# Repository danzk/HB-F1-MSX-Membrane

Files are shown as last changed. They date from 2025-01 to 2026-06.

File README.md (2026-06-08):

# MSX Hit Bit Keyboard Membranes

Replacement keyboard membranes for Sony MSX "Hit Bit" home computers.

This repository hosts one design per machine, each in its own directory, all
sharing a common KiCad footprint library.

## Variants

| Machine | Directory | Notes |
| --- | --- | --- |
| Sony HB-F1 | [hb-f1/](hb-f1/) | Original design |
| Sony HB-F1II | [hb-f1ii/](hb-f1ii/) | Reworked PCB with revised switch footprint |

Each variant directory contains its own `pcb/` (KiCad project), `gerber/`
(fabrication outputs) and `mech/` (mechanical drawings), plus a `doc/`
folder for any variant-specific images. Reference material and renders
shared across variants live in the top-level [doc/](doc/) directory.

## Shared footprint library

Both projects reference the same footprints in
[footprints/Sony_Hit_Bit.pretty/](footprints/Sony_Hit_Bit.pretty/) via each
project's `fp-lib-table` (`${KIPRJMOD}/../../footprints/Sony_Hit_Bit.pretty`).

## Manufacturing

See [doc/MANUFACTURING.md](doc/MANUFACTURING.md) for how to order the membrane
from JLCPCB as a 2-layer flexible PCB (stackup, order settings and stiffener
details).

## Other projects

Related keyboard membrane / replacement projects for other Sony MSX models:

- [RBSC/KeyboardMembrane_SonyF1Xx](https://github.com/RBSC/KeyboardMembrane_SonyF1Xx)
  — replacement membrane PCB and gerbers for the Sony HB-F1XV, HB-F1XD and
  HB-F1XDJ.
- [S0urceror/HB-F1XD-keyboard](https://github.com/S0urceror/HB-F1XD-keyboard)
  — KiCad PCB replacement for the Sony HB-F1XD MSX2 keyboard membrane.

## Tooling

2D mechanical drawings were performed with QCAD v3.31.2.7 — https://www.qcad.org/

Electronics were designed with KiCad v8.0.7 — https://www.kicad.org/

The PCB layout uses the font IBM Plex Sans — https://www.ibm.com/plex/

## Licence

Copyright Alexander Knapik 2025.

This source describes Open Hardware and is licensed under the CERN-OHL-W v2 or later.

You may redistribute and modify this documentation and make products
using it under the terms of the CERN-OHL-W v2 (https://cern.ch/cern-ohl).
This documentation is distributed WITHOUT ANY EXPRESS OR IMPLIED
WARRANTY, INCLUDING OF MERCHANTABILITY, SATISFACTORY QUALITY
AND FITNESS FOR A PARTICULAR PURPOSE. Please see the CERN-OHL-W v2
for applicable conditions.

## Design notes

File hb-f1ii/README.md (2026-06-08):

# MSX HB-F1II Keyboard Membrane

A replacement keyboard membrane for the Sony HB-F1II MSX home computer.

This variant reworks the HB-F1 PCB and uses the revised `Switch 2` footprint
from the shared footprint library.

See the [repository README](../README.md) for tooling and licence information.

**Warning this membrane has not yet been tested on real hardware!**

The source image for the HB-F1II is skewed, so there is no guarantee that the footprints for the arrow keys are in the correct location. 

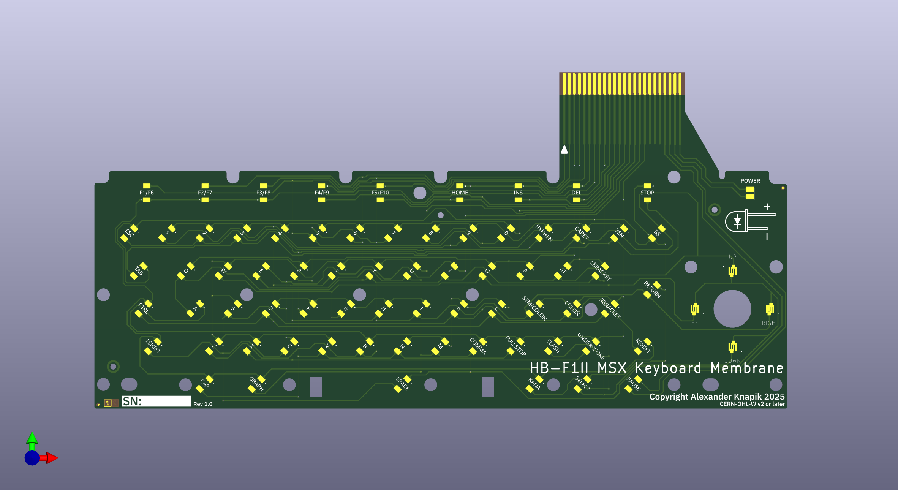
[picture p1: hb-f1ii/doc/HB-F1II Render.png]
Render

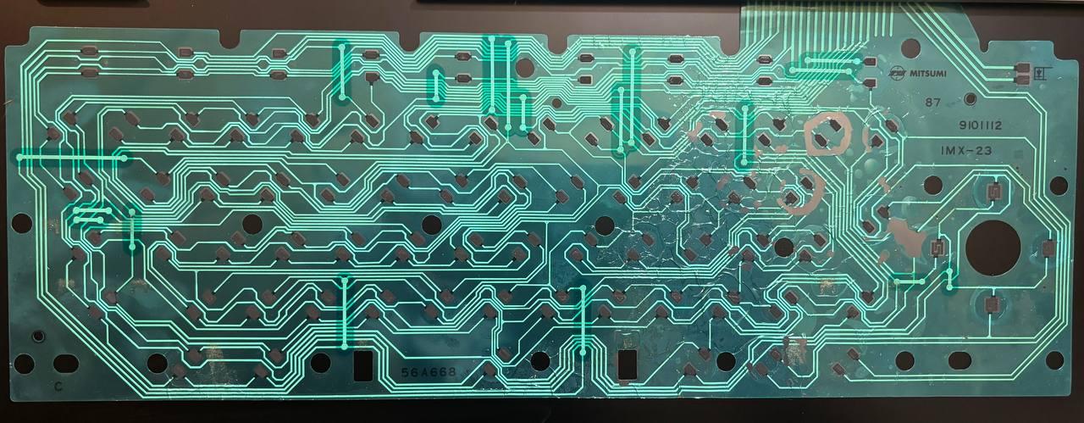
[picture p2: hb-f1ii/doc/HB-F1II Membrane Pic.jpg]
Membrane


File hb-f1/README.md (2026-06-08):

# MSX HB-F1 Keyboard Membrane

A replacement keyboard membrane for the Sony HB-F1 MSX home computer.

See the [repository README](../README.md) for tooling and licence information.

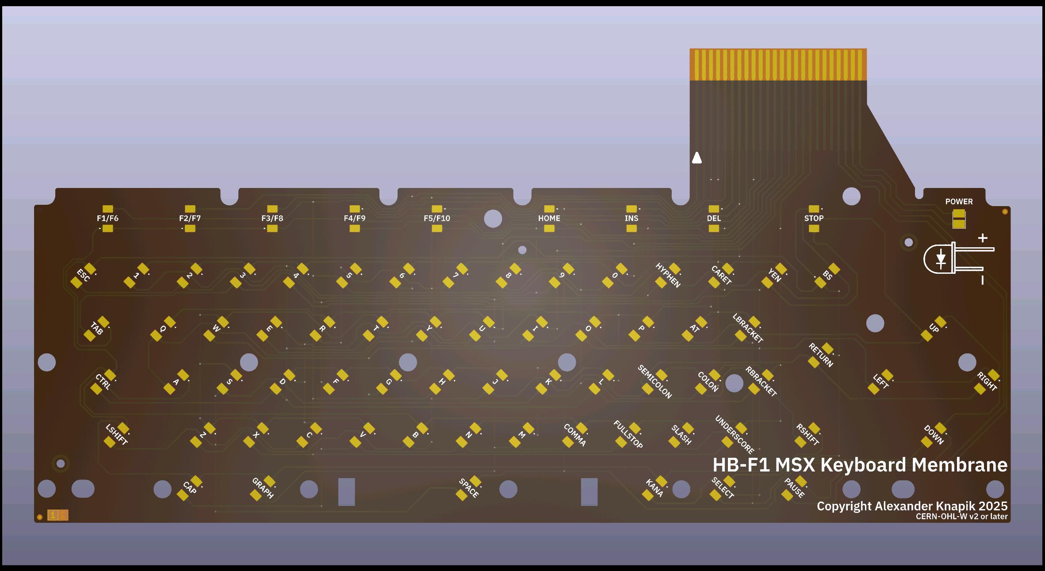
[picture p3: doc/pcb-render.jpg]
PCB Render

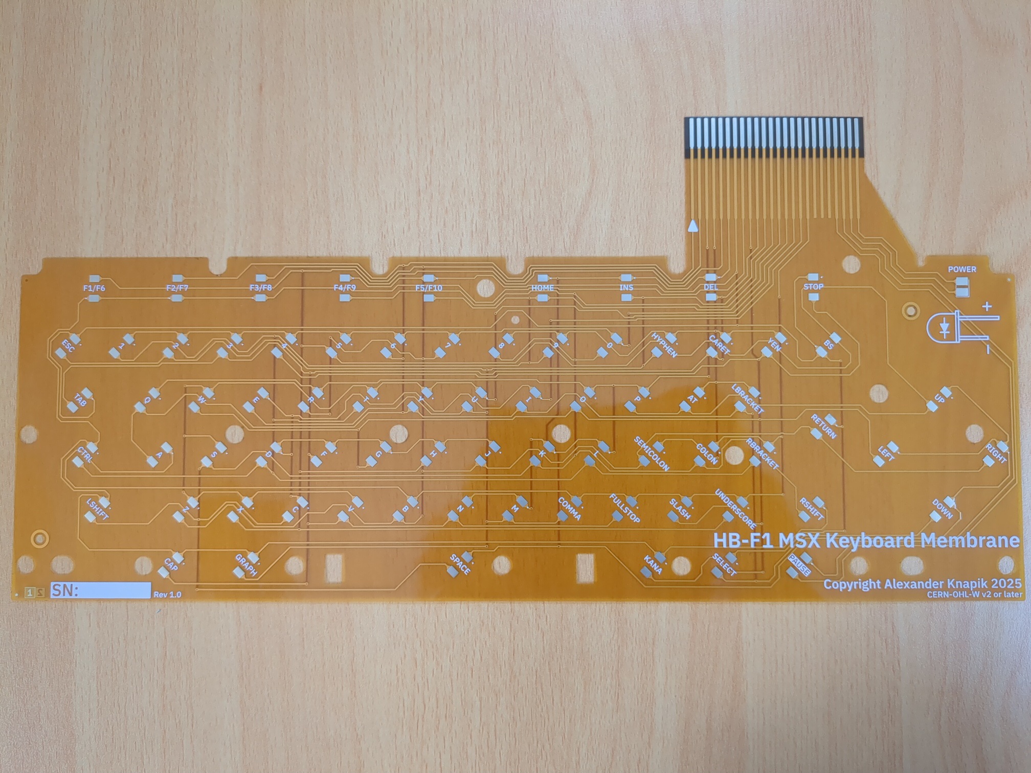
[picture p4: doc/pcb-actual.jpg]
PCB Actual

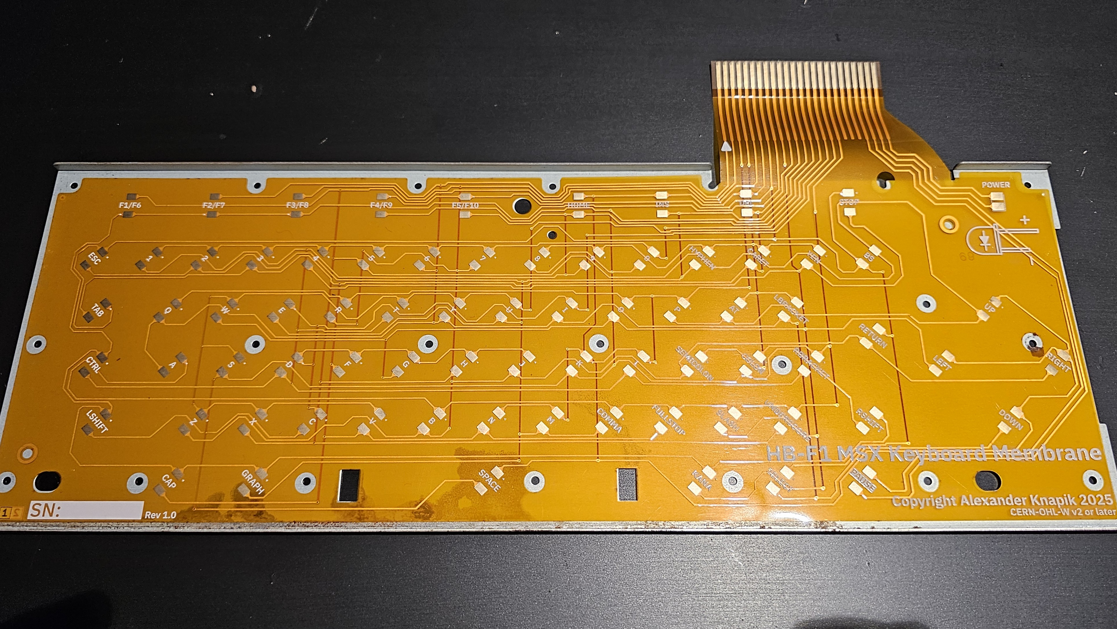
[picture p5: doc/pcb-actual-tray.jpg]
PCB Tray

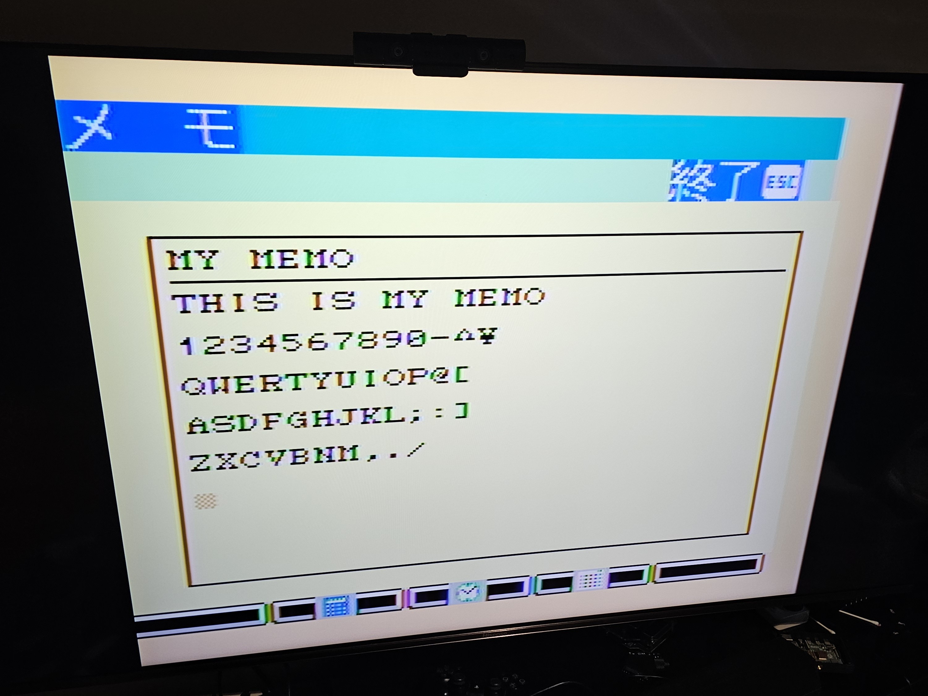
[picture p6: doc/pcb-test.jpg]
PCB TEST


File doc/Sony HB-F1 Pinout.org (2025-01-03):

Copyright Alexander Knapik 2025.

|-----+-------+-----+-----+--------+--------+--------+--------+--------+--------+-------|
| pin | 1     |   2 | 3   | 4      | 5      | 6      | 7      | 8      | 9      |    10 |
|-----+-------+-----+-----+--------+--------+--------+--------+--------+--------+-------|
|   1 | F2    |   6 | Q   | Y      | I      | [      | A      | SELECT | DOWN   |       |
|   2 | F3    |   7 | R   | RETURN | J      | ;      | Z      | B      | RIGHT  |       |
|   3 | Q     |   R | O   | P      | J      | K      | L      | N      | M      |       |
|   4 | 8     |   9 | -   | ^      | YEN    | [      | @      | ;      |        |       |
|   5 | F1    |   5 | BS  | P      | @      | H      | X      | _      | UP     |       |
|   6 | F6    |  F7 | F8  | SPACE  | UP     | DOWN   | LEFT   | RIGHT  |        |       |
|   7 | F4    |  F5 | ESC | TAB    | BS     | RETURN | F9     | SELECT |        |       |
|   8 | F1    |  F2 | F3  | CTRL   | LSHIFT | RSHIFT | GRAPH  | CAP    | KANA   |       |
|   9 | F9    |   4 | YEN | W      | O      | G      | /      | KANA   | LEFT   |       |
|  10 | F8    |   3 | ^   | TAB    | F      | V      | N      | .      | CAP    |       |
|  11 | F7    | ESC | 2   | -      | E      | U      | M      | ,      | GRAPH  |       |
|  12 | F4    |   8 | 0   | S      | K      | :      | LSHIFT | C      | RSHIFT | SPACE |
|  13 | F5    |  F6 | 1   | 9      | T      | CTRL   | D      | L      | ]      |       |
|  14 | 1     |   2 | 3   | 4      | 5      | 6      | 7      | 0      |        |       |
|  15 | W     |   T | Y   | U      | S      | Z      | X      | V      |        |       |
|  16 | E     |   I | D   | F      | G      | H      | J      | C      |        |       |
|  17 | A     |   : | ]   | B      | ,      | .      | /      | _      |        |       |
|  18 |       |     |     |        |        |        |        |        |        |       |
|  19 |       |     |     |        |        |        |        |        |        |       |
|  20 |       |     |     |        |        |        |        |        |        |       |
|  21 | PAUSE |     |     |        |        |        |        |        |        |       |
|  22 | PAUSE |     |     |        |        |        |        |        |        |       |
|  23 | LED   |     |     |        |        |        |        |        |        |       |
|  24 | LED   |     |     |        |        |        |        |        |        |       |
|-----+-------+-----+-----+--------+--------+--------+--------+--------+--------+-------|

|--------+-------+-------|
| Key    | Pin A | Pin B |
|--------+-------+-------|
| 0      |    14 |    12 |
| 1      |    14 |    13 |
| 2      |    14 |    11 |
| 3      |    14 |    10 |
| 4      |    14 |     9 |
| 5      |    14 |     5 |
| 6      |    14 |     1 |
| 7      |    14 |     2 |
| 8      |     4 |    12 |
| 9      |     4 |    13 |
| -      |     4 |    11 |
| ^      |     4 |    10 |
| YEN    |     4 |     9 |
| @      |     4 |     5 |
| [      |     4 |     1 |
| ;      |     4 |     2 |
| :      |    17 |    12 |
| ]      |    17 |    13 |
| ,      |    17 |    11 |
| .      |    17 |    10 |
| /      |    17 |     9 |
| _      |    17 |     5 |
| A      |    17 |     1 |
| B      |    17 |     2 |
| C      |    16 |    12 |
| D      |    16 |    13 |
| E      |    16 |    11 |
| F      |    16 |    10 |
| G      |    16 |     9 |
| H      |    16 |     5 |
| I      |    16 |     1 |
| J      |    16 |     2 |
| K      |     3 |    12 |
| L      |     3 |    13 |
| M      |     3 |    11 |
| N      |     3 |    10 |
| O      |     3 |     9 |
| P      |     3 |     5 |
| Q      |     3 |     1 |
| R      |     3 |     2 |
| S      |    15 |    12 |
| T      |    15 |    13 |
| U      |    15 |    11 |
| V      |    15 |    10 |
| W      |    15 |     9 |
| X      |    15 |     5 |
| Y      |    15 |     1 |
| Z      |    15 |     2 |
| LSHIFT |     8 |    12 |
| RSHIFT |     8 |    12 |
| CTRL   |     8 |    13 |
| GRAPH  |     8 |    11 |
| CAP    |     8 |    10 |
| KANA   |     8 |     9 |
| F1     |     8 |     5 |
| F2     |     8 |     1 |
| F3     |     8 |     2 |
| F4     |     7 |    12 |
| F5     |     7 |    13 |
| ESC    |     7 |    11 |
| TAB    |     7 |    10 |
| F9     |     7 |     9 |
| BS     |     7 |     5 |
| SELECT |     7 |     1 |
| RETURN |     7 |     2 |
| SPACE  |     6 |    12 |
| F6     |     6 |    13 |
| F7     |     6 |    11 |
| F8     |     6 |    10 |
| LEFT   |     6 |     9 |
| UP     |     6 |     5 |
| DOWN   |     6 |     1 |
| RIGHT  |     6 |     2 |
| PAUSE  |    21 |    22 |
| LED    |    23 |    24 |
|--------+-------+-------|

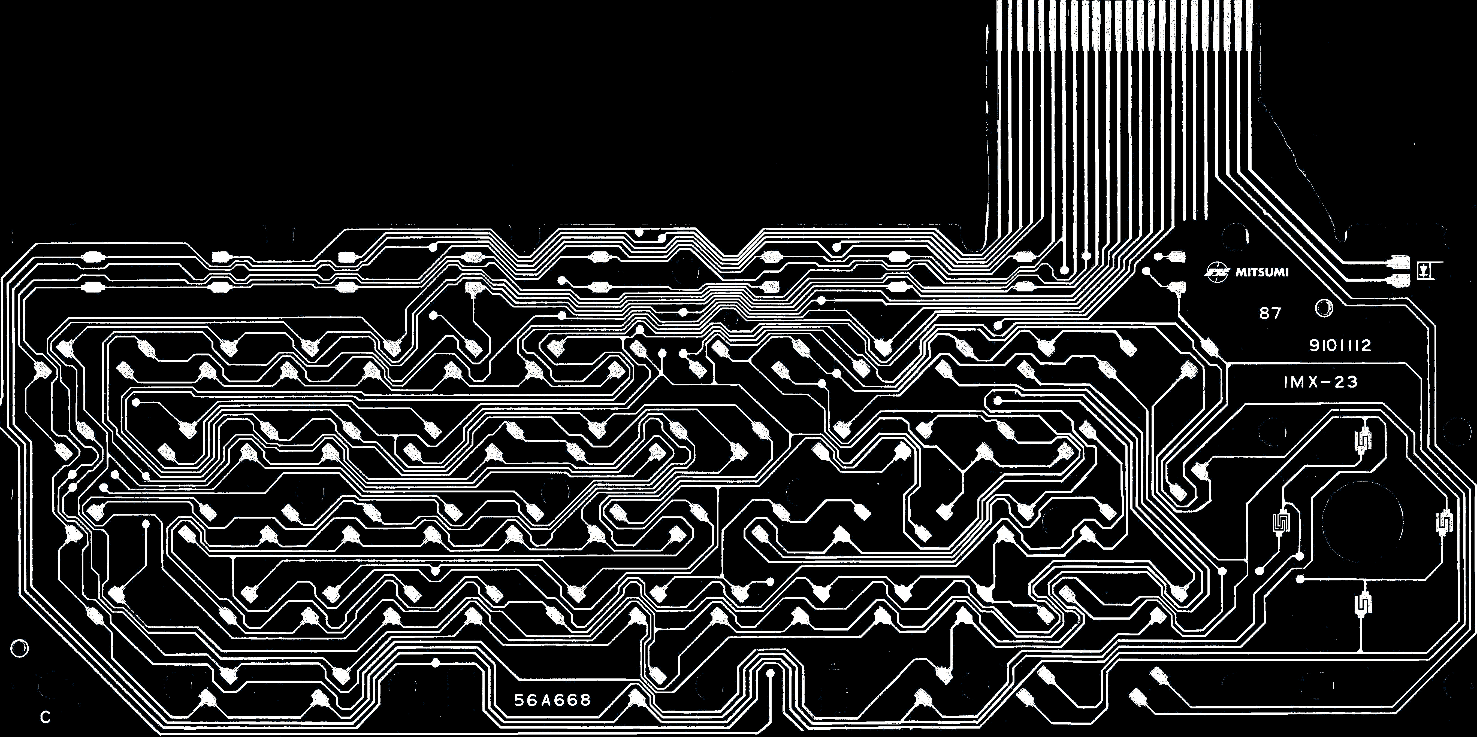
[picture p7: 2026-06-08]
hb-f1ii/doc/HB-F1II Membrane Scan.png

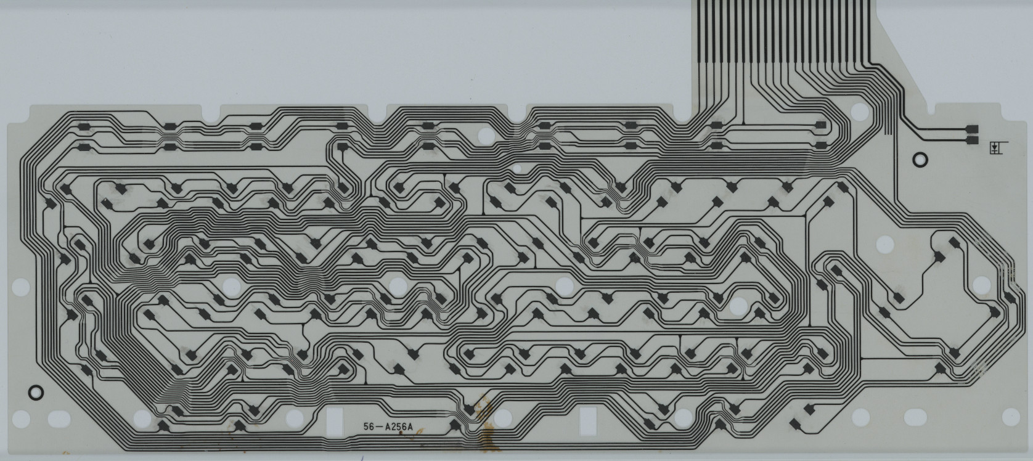
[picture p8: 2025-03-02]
doc/Sony HB-F1 Membrane Front Low Res.jpg

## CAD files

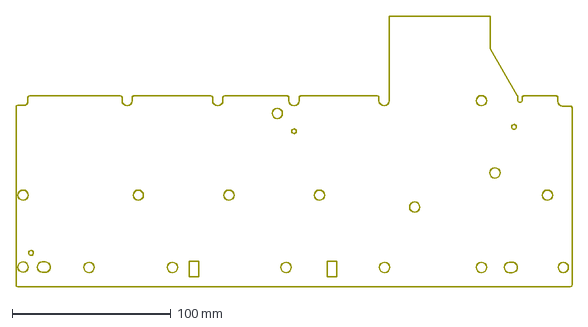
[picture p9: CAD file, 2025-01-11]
hb-f1ii/mech/Membrane Drawing.dxf
350.0 x 170.0 mm

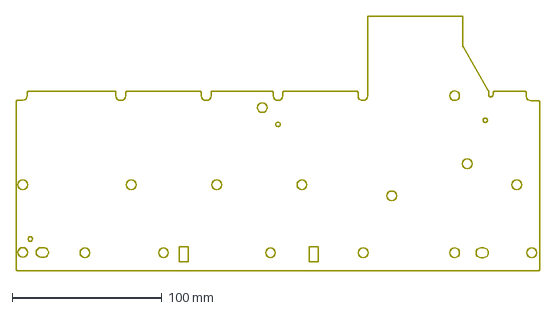
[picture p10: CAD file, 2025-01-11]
hb-f1ii/mech/Membrane Outline.dxf
350.0 x 170.0 mm

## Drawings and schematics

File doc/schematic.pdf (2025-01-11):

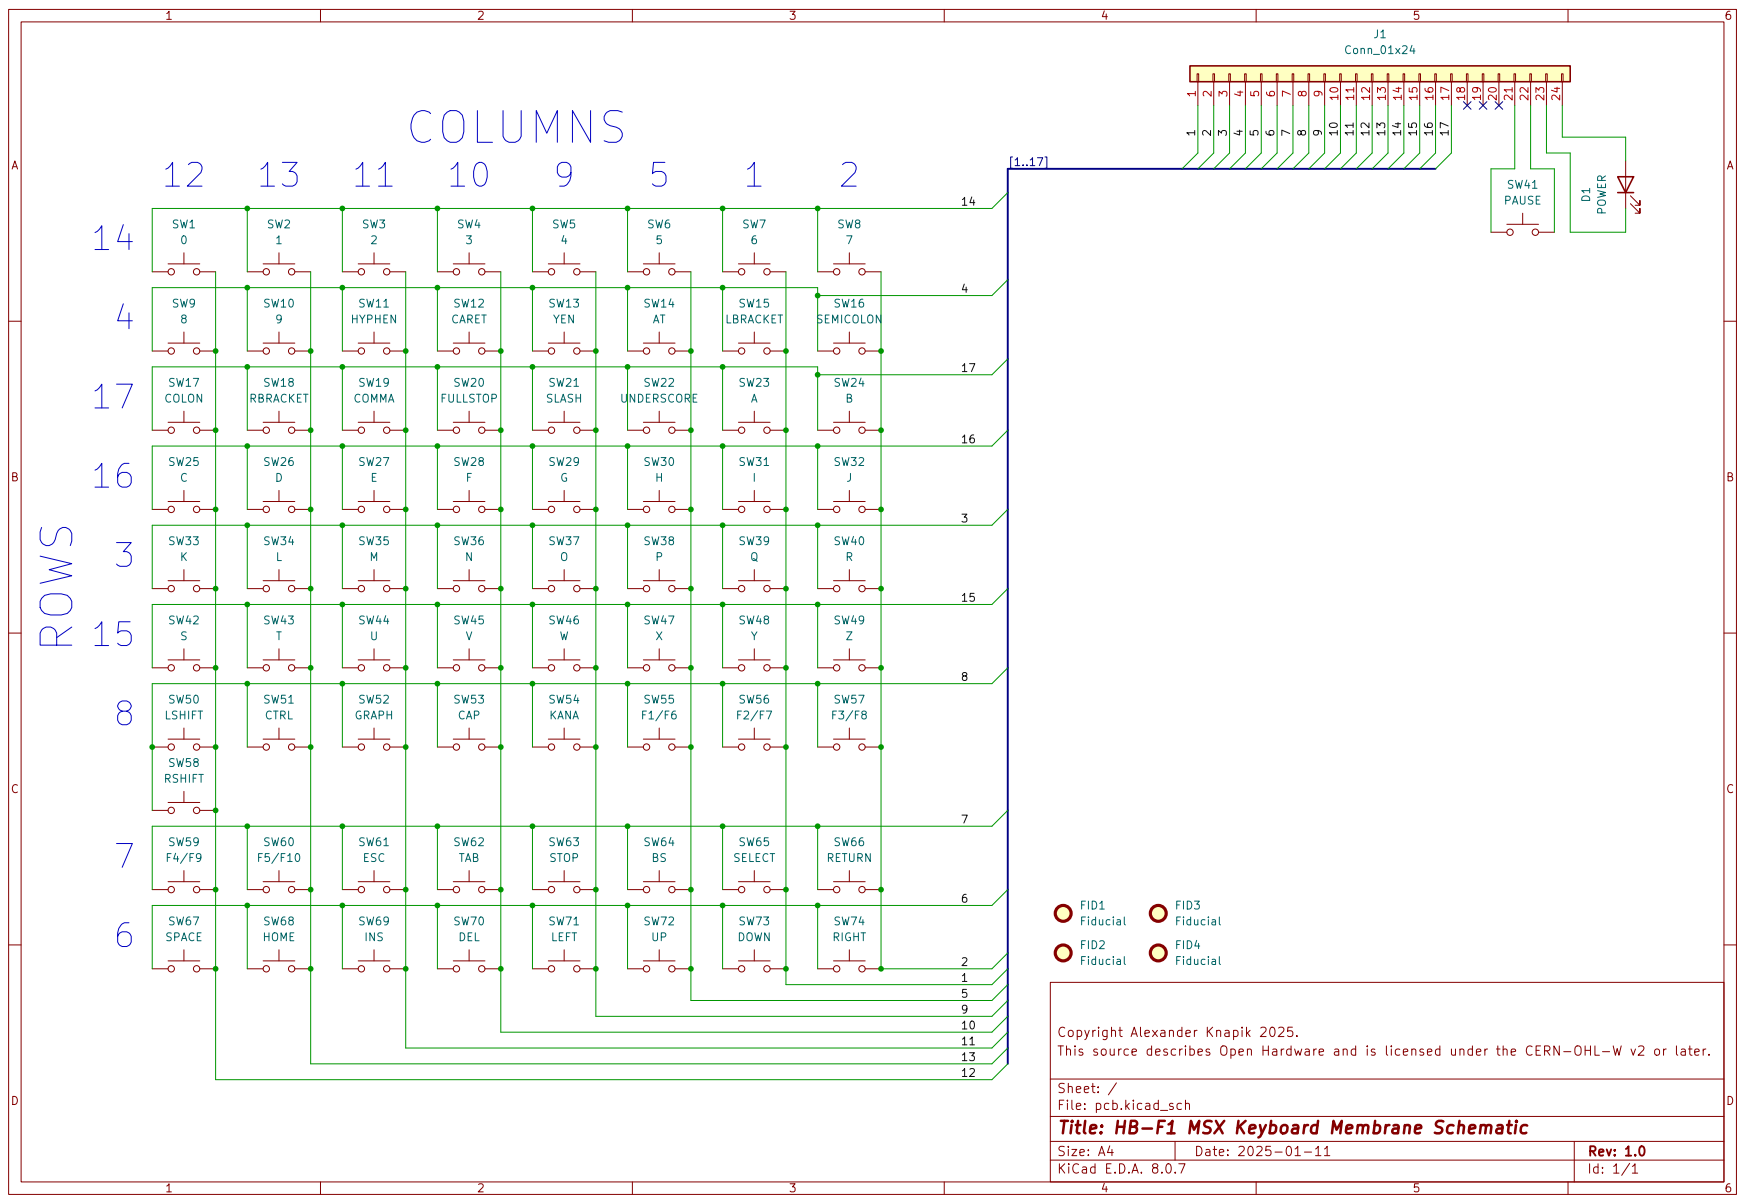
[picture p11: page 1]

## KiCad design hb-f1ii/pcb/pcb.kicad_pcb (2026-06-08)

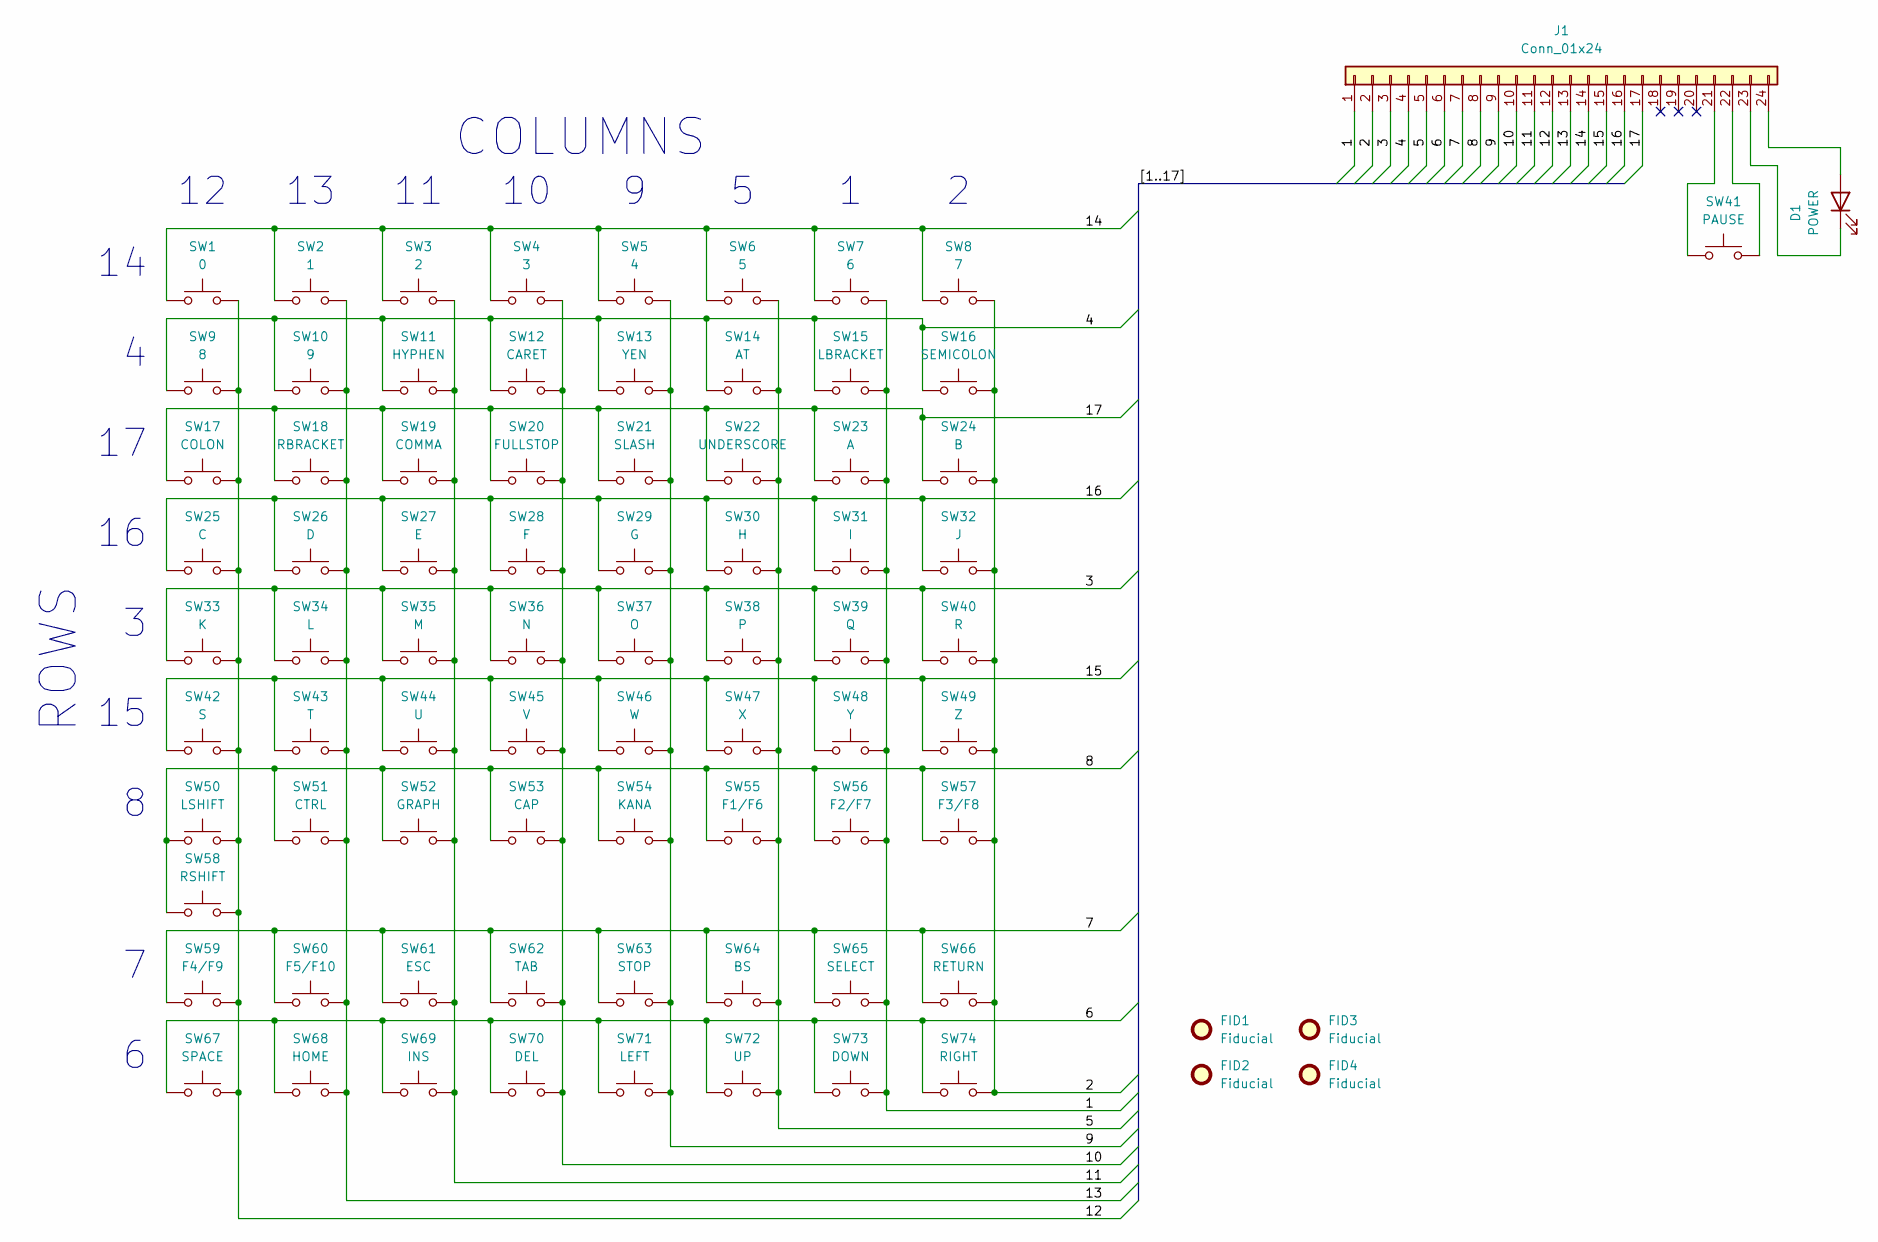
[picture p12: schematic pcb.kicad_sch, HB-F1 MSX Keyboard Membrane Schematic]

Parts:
D1: POWER; LED
FID1, FID2, FID3, FID4: Fiducial; Fiducial_1mm_Mask2mm
J1: Conn_01x24; Connector
SW1: 0; Switch
SW2: 1; Switch
SW3: 2; Switch
SW4: 3; Switch
SW5: 4; Switch
SW6: 5; Switch
SW7: 6; Switch
SW8: 7; Switch
SW9: 8; Switch
SW10: 9; Switch
SW11: HYPHEN; Switch
SW12: CARET; Switch
SW13: YEN; Switch
SW14: AT; Switch
SW15: LBRACKET; Switch
SW16: SEMICOLON; Switch
SW17: COLON; Switch
SW18: RBRACKET; Switch
SW19: COMMA; Switch
SW20: FULLSTOP; Switch
SW21: SLASH; Switch
SW22: UNDERSCORE; Switch
SW23: A; Switch
SW24: B; Switch
SW25: C; Switch
SW26: D; Switch
SW27: E; Switch
SW28: F; Switch
SW29: G; Switch
SW30: H; Switch
SW31: I; Switch
SW32: J; Switch
SW33: K; Switch
SW34: L; Switch
SW35: M; Switch
SW36: N; Switch
SW37: O; Switch
SW38: P; Switch
SW39: Q; Switch
SW40: R; Switch
SW41: PAUSE; Switch
SW42: S; Switch
SW43: T; Switch
SW44: U; Switch
SW45: V; Switch
SW46: W; Switch
SW47: X; Switch
SW48: Y; Switch
SW49: Z; Switch
SW50: LSHIFT; Switch
SW51: CTRL; Switch
SW52: GRAPH; Switch
SW53: CAP; Switch
SW54: KANA; Switch
SW55: F1/F6; Switch
SW56: F2/F7; Switch
SW57: F3/F8; Switch
SW58: RSHIFT; Switch
SW59: F4/F9; Switch
SW60: F5/F10; Switch
SW61: ESC; Switch
SW62: TAB; Switch
SW63: STOP; Switch
SW64: BS; Switch
SW65: SELECT; Switch
SW66: RETURN; Switch
SW67: SPACE; Switch
SW68: HOME; Switch
SW69: INS; Switch
SW70: DEL; Switch
SW71: LEFT; Switch
SW72: UP; Switch
SW73: DOWN; Switch
SW74: RIGHT; Switch

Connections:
/1: J1.1, SW7.2, SW15.2, SW23.2, SW31.2, SW39.2, SW48.2, SW56.2, SW65.2, SW73.2
/2: J1.2, SW8.2, SW16.2, SW24.2, SW32.2, SW40.2, SW49.2, SW57.2, SW66.2, SW74.2
/3: J1.3, SW33.1, SW34.1, SW35.1, SW36.1, SW37.1, SW38.1, SW39.1, SW40.1
/4: J1.4, SW9.1, SW10.1, SW11.1, SW12.1, SW13.1, SW14.1, SW15.1, SW16.1
/5: J1.5, SW6.2, SW14.2, SW22.2, SW30.2, SW38.2, SW47.2, SW55.2, SW64.2, SW72.2
/6: J1.6, SW67.1, SW68.1, SW69.1, SW70.1, SW71.1, SW72.1, SW73.1, SW74.1
/7: J1.7, SW59.1, SW60.1, SW61.1, SW62.1, SW63.1, SW64.1, SW65.1, SW66.1
/8: J1.8, SW50.1, SW51.1, SW52.1, SW53.1, SW54.1, SW55.1, SW56.1, SW57.1, SW58.1
/9: J1.9, SW5.2, SW13.2, SW21.2, SW29.2, SW37.2, SW46.2, SW54.2, SW63.2, SW71.2
/10: J1.10, SW4.2, SW12.2, SW20.2, SW28.2, SW36.2, SW45.2, SW53.2, SW62.2, SW70.2
/11: J1.11, SW3.2, SW11.2, SW19.2, SW27.2, SW35.2, SW44.2, SW52.2, SW61.2, SW69.2
/12: J1.12, SW1.2, SW9.2, SW17.2, SW25.2, SW33.2, SW42.2, SW50.2, SW58.2, SW59.2, SW67.2
/13: J1.13, SW2.2, SW10.2, SW18.2, SW26.2, SW34.2, SW43.2, SW51.2, SW60.2, SW68.2
/14: J1.14, SW1.1, SW2.1, SW3.1, SW4.1, SW5.1, SW6.1, SW7.1, SW8.1
/15: J1.15, SW42.1, SW43.1, SW44.1, SW45.1, SW46.1, SW47.1, SW48.1, SW49.1
/16: J1.16, SW25.1, SW26.1, SW27.1, SW28.1, SW29.1, SW30.1, SW31.1, SW32.1
/17: J1.17, SW17.1, SW18.1, SW19.1, SW20.1, SW21.1, SW22.1, SW23.1, SW24.1
unnamed: D1.2 (A), J1.24
unnamed: D1.1 (K), J1.23
unnamed: J1.21, SW41.1
unnamed: J1.22, SW41.2

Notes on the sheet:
COLUMNS
ROWS

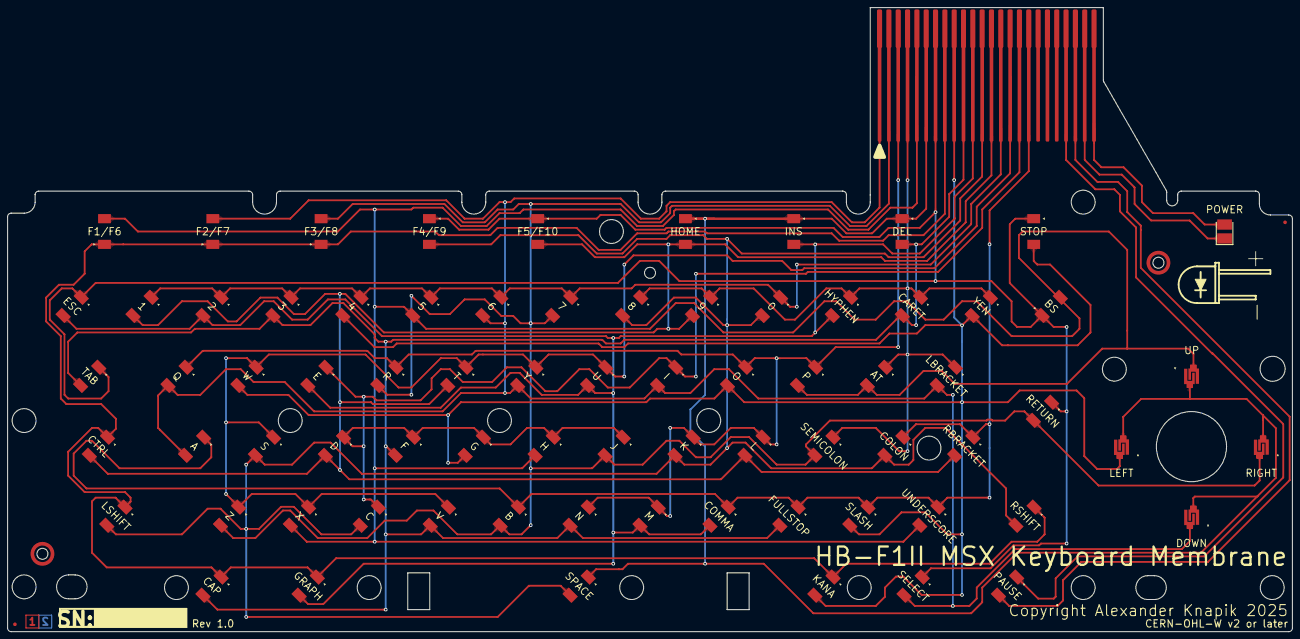
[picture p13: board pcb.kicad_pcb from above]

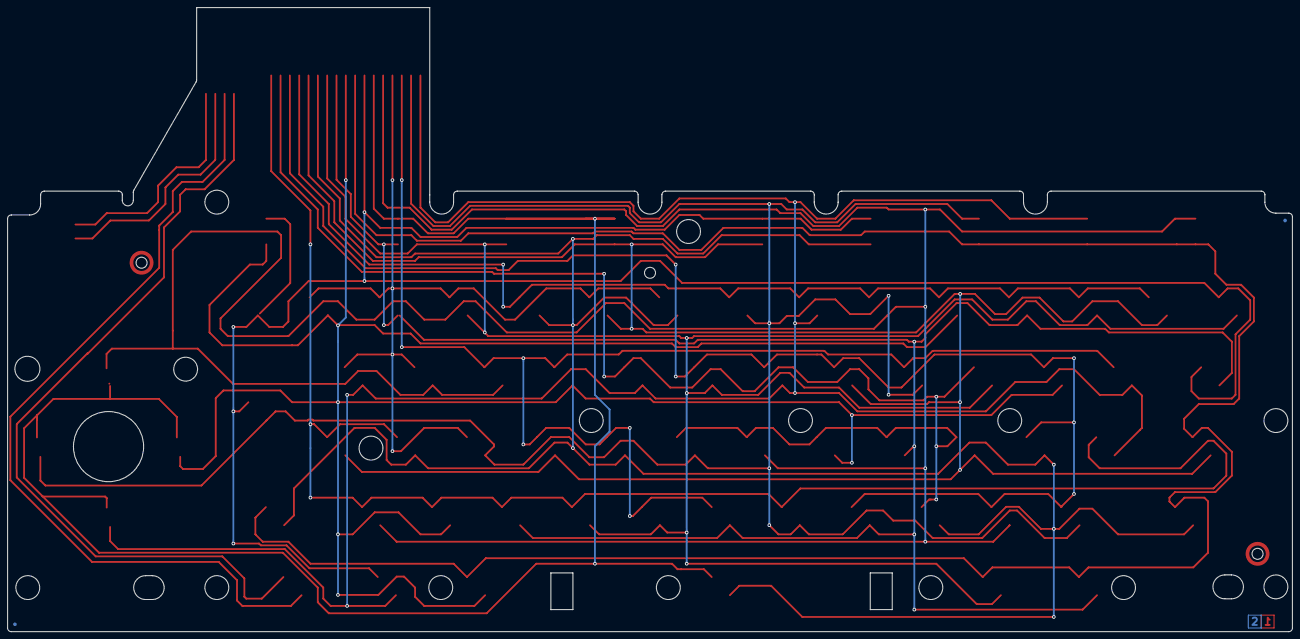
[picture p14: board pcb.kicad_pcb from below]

Board: 2 copper layers, 350.0 x 170.0 mm, 80 parts (2 on the bottom side), 21 nets.

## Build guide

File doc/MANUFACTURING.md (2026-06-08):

# Manufacturing the Membrane at JLCPCB (Flexible PCB)

This guide explains how to order the Hit Bit keyboard membrane from
[JLCPCB](https://jlcpcb.com/) as a **2-layer Flexible PCB (FPC)**. It applies to
both variants — substitute the variant's `gerber/` folder accordingly:

| Variant | Gerber folder |
| --- | --- |
| Sony HB-F1 | [hb-f1/gerber/](../hb-f1/gerber/) |
| Sony HB-F1II | [hb-f1ii/gerber/](../hb-f1ii/gerber/) |

> **Note (HB-F1II):** this variant has not yet been verified on real hardware.
> See [hb-f1ii/README.md](../hb-f1ii/README.md) before ordering.

All values below are taken from the **Board Characteristics** and **Stiffener
Characteristics** tables and the layer stackup embedded in the KiCad PCB (the
`User.Comments` layer). They are reproduced here so they can be matched against
the JLCPCB order form.

---

## 1. Files to upload

JLCPCB accepts a single ZIP of the Gerber/drill set. Zip the contents of the
variant's `gerber/` folder. The required files are:

| File | Purpose |
| --- | --- |
| `pcb-F_Cu.gbr` | Top copper |
| `pcb-B_Cu.gbr` | Bottom copper |
| `pcb-F_Mask.gbr` | Top coverlay opening |
| `pcb-B_Mask.gbr` | Bottom coverlay opening |
| `pcb-F_Silkscreen.gbr` | Top legend (direct print) |
| `pcb-B_Silkscreen.gbr` | Bottom legend (direct print) |
| `pcb-Edge_Cuts.gbr` | Board outline **and internal cut-outs** |
| `pcb-PTH.drl` | Plated holes |
| `pcb-NPTH.drl` | Non-plated holes |
| `pcb-User_1.gbr` | **Stiffener outline** (65 × 15 mm PI stiffener) |
| `pcb-job.gbrjob` | Gerber job metadata (optional but helpful) |

You can omit the paste layers (`pcb-F_Paste.gbr`, `pcb-B_Paste.gbr`) and
`pcb-User_Comments.gbr` — there is no SMT assembly, and the comments layer is
documentation only.

> If you need to regenerate these, open the project in KiCad 10, then
> **File → Plot** (select the layers above, Gerber format) and
> **File → Fabrication Outputs → Drill Files** (Excellon, PTH/NPTH separated).

---

## 2. JLCPCB order configuration

Set **Base Material** to **`Flex`** first — the flex-specific fields (polyimide
thickness, coverlay, flex copper weight, stiffener) only appear after that.
Field labels and option strings below are quoted verbatim from the JLCPCB quote
form (<https://cart.jlcpcb.com/quote>); the right-hand column is the value
encoded in the PCB.

| JLCPCB field | Selection | Source |
| --- | --- | --- |
| Base Material | **`Flex`** | Polyimide stackup |
| Layers | **`2`** | Copper Layer Count |
| Dimensions (single piece) | **350 × 170 mm** | Board overall dimensions |
| Different Design | `1` | — |
| Delivery Format | `Single PCB` | — |
| PCB Thickness (flex) | **≈ 0.1 mm** (nearest flex option) | Board Thickness 0.1034 mm |
| Coverlay colour | **`Yellow`** | F.Mask / B.Mask colour |
| Outer Copper Weight | **`1/3 oz`** (≈12 µm; lightest flex option) | "12 µm finish copper (1/3 Oz.)" |
| Surface Finish | **`ENIG`** | Copper Finish |
| Gold Fingers | `No` | see note below |
| Castellated Holes | `No` | Castellated pads |
| Stiffener | **`Polyimide`** — see section 3 | Stiffener required |
| EMI Shielding Film | (leave off) | — |

> The `PCB Thickness` and `Outer Copper Weight` option lists change once
> `Flex` is selected (the form's default lists are for FR-4). Pick the flex
> value closest to the spec — ~0.1 mm thickness and the lightest copper
> (1/3 oz / 12 µm).

For reference, the design rules are well inside JLCPCB's FPC limits:
min track/spacing **0.25 mm / 0.25 mm**, min hole **0.5 mm**, and vias are
tented.

**Gold Fingers:** the design marks the cable tail as an edge connector, but the
exposed contacts there are simply coverlay openings plated by the **ENIG**
finish — leave `Gold Fingers` set to `No` (that option adds bevelled, thick
gold edge fingers, which the FFC/ZIF connector does not need).

---

## 3. Stiffener

The tail that inserts into the keyboard connector needs a stiffener so it has
enough thickness and rigidity for the connector.

| Property | Value |
| --- | --- |
| Required | Yes |
| Material | **Polyimide (PI)** |
| Stiffener thickness | **0.225 mm** (use the nearest available, e.g. 0.20–0.25 mm) |
| Overall size | 65 × 15 mm |
| Side | **Bottom** (B.Stiffener) — copper on stiffener side: No |
| Total thickness at tail | ≈ 0.289 mm (0.1034 mm flex + stiffener) |
| Gerber layer defining region | **`User.1`** (`pcb-User_1.gbr`) |

When ordering, set **`Stiffener`** to **`Polyimide`** (the other options are
`Without`, `FR4`, `Stainless Steel` and `3M Tape`). In the order remarks,
instruct JLCPCB that the stiffener location/outline is defined by the `User.1`
gerber layer (`pcb-User_1.gbr`) and goes on the bottom side. The target total
thickness at the contact tail is ~0.3 mm to suit the MSX keyboard FFC connector.

---

## 4. Layer stackup (reference)

| # | Layer | Type | Material | Thickness | Colour |
| --- | --- | --- | --- | --- | --- |
| 1 | F.Silkscreen | Top Silk Screen | Direct Printing | — | White |
| 2 | F.Paste | Top Solder Paste | — | — | — |
| 3 | F.Mask | Top Solder Mask (coverlay) | Coverlay + Adhesive | 0.0275 mm | Yellow |
| 4 | F.Cu | Copper | — | 0.012 mm (1/3 oz) | — |
| 5 | Dielectric 1 | Core | Polyimide | 0.025 mm | — |
| 6 | B.Cu | Copper | — | 0.012 mm (1/3 oz) | — |
| 7 | B.Mask | Bottom Solder Mask (coverlay) | Coverlay + Adhesive | 0.0275 mm | Yellow |
| 8 | B.Paste | Bottom Solder Paste | — | — | — |
| 9 | B.Silkscreen | Bottom Silk Screen | Direct Printing | — | White |
| 10 | B.Stiffener | Bottom Stiffener | Polyimide | 0.225 mm | — |

Base flex thickness (layers 3–7): **≈ 0.1034 mm**.

---

## 5. Things to check before paying

- **Board size.** The 350 × 170 mm HB-F1 board has already been manufactured at
  JLCPCB, so the size is within their single-piece FPC limit. The HB-F1II board
  shares the same outline dimensions.
- **Cut-outs.** The design contains internal cut-outs ("Cut-out in design:
  Yes"); confirm they are read from `pcb-Edge_Cuts.gbr` in JLCPCB's Gerber
  viewer.
- **Stiffener placement.** Verify in the Gerber viewer that the stiffener
  region (`User.1`) lands on the connector tail, on the bottom side.
- **Coverlay openings.** Check that the contact fingers and any test points are
  exposed (coverlay opened) and everything else is covered.
- If anything is ambiguous, raise it in the JLCPCB order remarks or via their
  review chat before production.

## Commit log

2025-01-03 Membrane 2D Drawing
    [Membrane Drawing.dxf]
2025-01-03 Completed schematics
    [Membrane Drawing.dxf, pcb.kicad_pcb, pcb.kicad_sch]
2025-01-03 Component placement
    [pcb.kicad_pcb, pcb.kicad_sch]
2025-01-05 PCB stackup definitions
    [pcb.kicad_pcb]
2025-01-05 Track routing
    [pcb.kicad_pcb]
2025-01-06 Updating footprints and adding PCB labels
    [pcb.kicad_pcb]
2025-01-06 README.md adding PCB render
2025-01-07 PCB fixing position errors and adding labels
    [pcb.kicad_pcb, pcb.kicad_sch]
2025-01-07 PCB adding fiducials
    [pcb.kicad_pcb, pcb.kicad_sch]
2025-01-07 Generating gerber files
    [pcb-B_Cu.gbr, pcb-B_Mask.gbr, pcb-B_Paste.gbr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]
2025-01-07 Adding PDF schematic to /doc
2025-01-07 PCB via fiducials and routing optimisations
    [pcb-B_Cu.gbr, pcb-B_Mask.gbr, pcb-B_Paste.gbr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]
2025-01-11 Reviewing PCB and updating switch spacing
    Changed soldermask layer on the connector to not be along the whole
    trace. Reviewed the pinout of all the switches and confirmed they're
    good. Reviewed the spacing of the switches and found errors, I have
    moved them but am yet to reroute the traces. Updated the teardrops to be
    curved.
    [Membrane Drawing.dxf, Membrane Outline.dxf, pcb.kicad_pcb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]
2025-01-11 Rerouted the deleted traces
    [pcb.kicad_pcb]
2025-01-11 Adding stiffener and fab notes
    [pcb-B_Cu.gbr, pcb-B_Mask.gbr, pcb-B_Paste.gbr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]
2025-01-11 Adding serial number label
    [pcb-B_Cu.gbr, pcb-B_Mask.gbr, pcb-B_Paste.gbr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]
2025-01-11 Reworked PCB and stiffener thickness
    [pcb-B_Cu.gbr, pcb-B_Mask.gbr, pcb-B_Paste.gbr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]
2025-01-11 Using knockout text for pause key
    [pcb-B_Cu.gbr, pcb-B_Mask.gbr, pcb-B_Paste.gbr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]
2025-03-02 Updated PCB to Support HBF1II
    [pcb.kicad_pcb]
2025-03-02 Added Render and cleaned up traces
    [pcb.kicad_pcb]
2026-06-08 Restructure HB-F1 into variant subdirectory
    Move the HB-F1 KiCad project, gerbers, docs and mechanical drawings
    under hb-f1/ and hoist the shared Sony_Hit_Bit footprint library to a
    top-level footprints/ directory. Update fp-lib-table to reference the
    shared library and ignore VSCode local history.
    Prepares the repo to host multiple Hit Bit membrane variants side by
    side (HB-F1, HB-F1II).
    [Membrane Drawing.dxf, Membrane Outline.dxf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]
2026-06-08 Restructure HB-F1II into variant subdirectory
    Move the HB-F1II KiCad project, gerbers, docs and mechanical drawings
    under hb-f1ii/ and hoist the shared Sony_Hit_Bit footprint library
    (including the F1II Switch 2 footprint) to a top-level footprints/
    directory. Update fp-lib-table to reference the shared library.
    Mirrors the hb-f1/ layout so both variants can be merged onto one
    branch without colliding on the shared pcb.kicad_pcb filename.
    [Membrane Drawing.dxf, Membrane Outline.dxf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]
2026-06-08 Add top-level variant index and per-variant READMEs
    Turn the root README into an index linking the HB-F1 and HB-F1II
    variants and documenting the shared footprint library layout. Add
    focused READMEs inside each variant directory.
2026-06-08 Dedupe shared docs into a top-level doc/ directory
    The HB-F1 and HB-F1II doc folders held 12 byte-identical files
    (keyboard/membrane reference images, pinout and shared PCB renders).
    Consolidate them into a single root doc/ and keep only the three
    HB-F1II-specific images under hb-f1ii/doc/. Update README image links
    accordingly.
2026-06-08 Update to KiCad 10
2026-06-08 Add JLCPCB flexible PCB manufacturing guide
    Document how to order the membrane from JLCPCB as a 2-layer flex PCB,
    derived from the Board/Stiffener Characteristics and stackup on the
    User.Comments layer: file set, order settings, the polyimide stiffener
    (User.1 layer) and a pre-order checklist. Link it from the root README.
2026-06-08 Align manufacturing guide wording with JLCPCB quote form
    Use the verbatim field labels and option strings from the JLCPCB FPC
    order form (Base Material 'Flex', Stiffener 'Polyimide', Surface Finish
    'ENIG', Gold Fingers/Castellated Holes 'No', Delivery Format 'Single
    PCB'). Note that the PCB Thickness and Outer Copper Weight option lists
    switch to flex values only after Base Material is set to Flex.
2026-06-08 Note HB-F1 board has been manufactured at JLCPCB
    The 350x170 mm size is confirmed within JLCPCB's flex limit since the
    HB-F1 board has been fabricated; HB-F1II shares the same outline.
